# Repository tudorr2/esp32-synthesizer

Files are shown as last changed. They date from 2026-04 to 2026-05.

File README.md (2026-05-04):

---








---

## ◈

It's a tiny standalone synthesizer built from scratch on a handmade PCB, housed in a 3D-printed PLA enclosure. It generates polyphonic sawtooth wave audio through a low-pass filter with 3-voice detuning — all in real-time on the ESP32's DAC output, amplified through a PAM8403 into a 3mm speaker.

> **Inspired by and adapted from** → [`todbot/mozzi_experiments`](https://github.com/todbot/mozzi_experiments)
> The core logic and tone architecture draws heavily from todbot's work. I translated the original Python-based concepts to C++, rewired the patterns, reworked the tone arrays, and adapted the whole thing to run on the ESP32.

---

## ◈ Hardware

| Component | Role |
|---|---|
| **ESP32** (30-pin dev board) | Brain — runs audio ISR + sequencer logic |
| **PAM8403** | Class-D audio amplifier module |
| **40mm Speaker** | Audio output |
| **2× Potentiometers** | Root note + BPM control |
| **2× Tactile Buttons** | Pattern change + transpose control |
| **1× Slide/Toggle Switch** | Power / standby gate |
| **Handmade PCB** | Point-to-point etched board |
| **3D Printed PLA Case** | Custom enclosure, designed to fit the PCB snugly |

---

## ◈ Photos

## ◈ 3D Printed Case

> 📷 *PLA case 
case

---

> 📷 *Board 
board

---

>📷 *3D Model
3dcase

---

## ◈ Pin Map

```
ESP32 GPIO 36  ──  Knob A       (Root Note)
ESP32 GPIO 39  ──  Knob B       (BPM)
ESP32 GPIO 18  ──  Button A     (Change Pattern)
ESP32 GPIO 19  ──  Button B     (Transpose Step)
ESP32 GPIO 25  ──  DAC Out      → PAM8403 input
ESP32 GPIO 22  ──  LED          (Note trigger indicator)
ESP32 GPIO 15  ──  Power Switch 
```

---

## ◈ Controls

### 🎛 Knob A — Root Note
Sweeps the root note from **C1 (24)** to **C5 (72)**.
Turning it changes the key everything plays in — low and bassy to bright and cutting.

### 🎛 Knob B — Tempo (BPM)
Sets the playback speed from **40 BPM** to **180 BPM**.
Changes take effect immediately mid-pattern.

### 🔘 Button A — Cycle Pattern
Steps through the **15 built-in arpeggio patterns** one by one.
Each press advances to the next motif. Cycles back to the first after the last.

### 🔘 Button B — Transpose Steps
Cycles through **0 / 1 / 2 transpose steps** applied per loop.
With transpose active, each loop of the pattern shifts up by one octave (12 semitones), then wraps back — creating climbing or cascading phrases.

---

## ◈ Patterns

15 patterns, each 4 steps long. Intervals are in semitones from the root:

| # | Name | Steps | Character |
|---|---|---|---|
| 0 | `major` | 0, 4, 7, 12 | Bright, uplifting |
| 1 | `minor7th` | 0, 3, 7, 10 | Moody, jazzy edge |
| 2 | `diminished` | 0, 3, 6, 3 | Tense, unsettled |
| 3 | `suspended4th` | 0, 5, 7, 12 | Open, floating |
| 4 | `octaves` | 0, 12, 0, −12 | Classic octave pump |
| 5 | `octaves2` | 0, 12, 24, −12 | Wide, dramatic sweep |
| 6 | `octaves3` | 0, −12, −12, 0 | Deep sub-drop |
| 7 | `new1` | 0, 1, 1, 1 | Chromatic crawl |
| 8 | `new2` | 0, 12, 12, 12 | Locked-octave pulse |
| 9 | `power` | 0, 7, 12, 7 | Power chord vibe |
| 10 | `jazzy` | 0, 4, 7, 11 | Major 7th, smooth |
| 11 | `fifth-jump` | 0, 12, 7, 19 | Leaping fifths |
| 12 | `glitchy` | 0, 6, 13, 5 | Dissonant, broken |
| 13 | `leap` | 0, 30, 20, 10 | Wild interval jumps |
| 14 | `root` | 0, 0, 0, 0 | Drone / root lock |

---

## ◈ Code

The project is split into two files:

- Replaced Mozzi's audio scheduler with `esp_timer` periodic ISR at 44.1kHz
- Rewrote all note/timing logic in fixed-step float arithmetic
- Added 3-voice detuned oscillator chorus
- Reworked the arpeggio/motif tables with new patterns (`glitchy`, `leap`, `new1`, `new2`, `power`, `fifth-jump`)

> Full credit to **[todbot](https://github.com/todbot)** whose `mozzi_experiments` repo was the direct inspiration and starting point for the pattern sequencer architecture. This is an adaptation — most of the higher-level motif/sequencer logic structure came from his work.

---

## ◈Credits

-Concept and sequencer architecture adapted from **[todbot/mozzi_experiments](https://github.com/todbot/mozzi_experiments)**

---

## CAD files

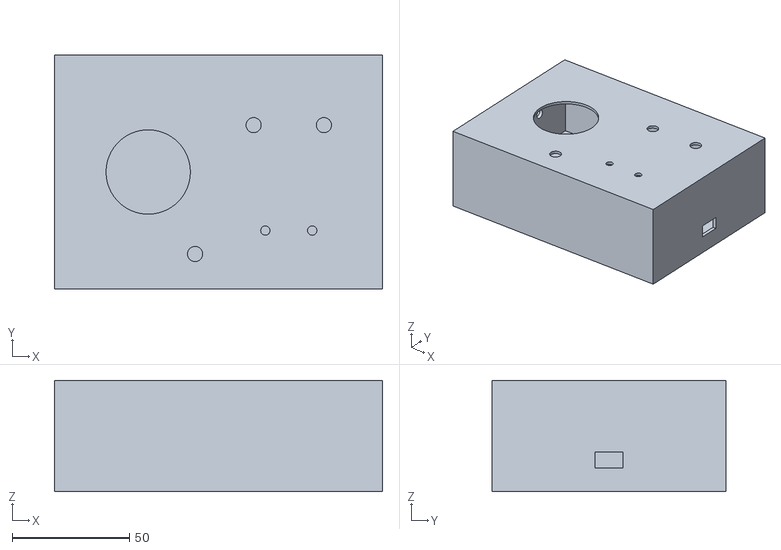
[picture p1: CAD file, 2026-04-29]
3d-case/case_esp32.stl
140.0 x 100.0 x 47.5

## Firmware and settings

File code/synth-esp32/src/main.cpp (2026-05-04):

#include <Arduino.h>
#include <driver/dac.h>
#include <esp_timer.h>
#include "lib.h"

#define PIN_KNOB_A 36
#define PIN_KNOB_B 39
#define PIN_BUTTON_A 14 // transpose steps
#define PIN_BUTTON_B 27 // mot pattern
#define PIN_DAC 25
#define PIN_LED 22
#define POWER_SW 15

#define SAMPLE_RATE 44100 // khz
#define NUM_VOICES 3
#define WAVE_LEN 512

int16_t wave_saw[WAVE_LEN];

struct Voice
{
  float phase;
  float freq;
  float lpf_out;
  float lpf_cutoff;
};
Voice voices[NUM_VOICES];

volatile float amp_level = 0.0f; // changes inside the isr
volatile float amp_target = 0.0f;
const float ATTACK_RATE = 1.0f / (0.01f * SAMPLE_RATE); // how fast it goes to 100; fade-in rate
const float RELEASE_RATE = 1.0f / (0.3f * SAMPLE_RATE);

float knobAval = 0, knobBval = 0;
const float KNOB_FILTER = 0.8f;

bool lastBtnA = HIGH, lastBtnB = HIGH;
unsigned long lastBtnAms = 0, lastBtnBms = 0;
const unsigned long DEBOUNCE_MS = 50; // waiting period after the btn press

Motif motif;

float midi_to_hz(int note)
{
  return 440.0f * powf(2.0f, (note - 69) / 12.0f);
}

float map_range(float s, float a1, float a2, float b1, float b2)
{
  return b1 + ((s - a1) * (b2 - b1) / (a2 - a1));
}

void note_on(int n)
{
  Serial.printf("  note on  %d\n", n);
  digitalWrite(PIN_LED, HIGH);

  float fo = midi_to_hz(n);
  for (int i = 0; i < NUM_VOICES; i++)
  {
    voices[i].freq = fo * (1.0f + i * 0.007f);
    float cutoff = (fo * 8.0f) / (SAMPLE_RATE / 2.0f);
    voices[i].lpf_cutoff = constrain(cutoff, 0.05f, 0.9f);
  }
  amp_target = 1.0f;
}

void note_off(int n)
{
  Serial.printf("  note off %d\n", n);
  digitalWrite(PIN_LED, LOW);
  amp_target = 0.0f;
}

void audio_isr(void *arg) // interrupt service routine
{

  // volume fade-in
  if (amp_level < amp_target)
  {
    amp_level += ATTACK_RATE;
    if (amp_level > amp_target)
      amp_level = amp_target;
  } // fade-out
  else if (amp_level > amp_target)
  {
    amp_level -= RELEASE_RATE;
    if (amp_level < 0.0f)
      amp_level = 0.0f;
  }

  if (amp_level <= 0.001f)
  {
    dacWrite(PIN_DAC, 128);
    return;
  }

  float mixed = 0.0f;
  for (int v = 0; v < NUM_VOICES; v++)
  {
    voices[v].phase += voices[v].freq / (float)SAMPLE_RATE; // phase accumulator
    if (voices[v].phase >= 1.0f)
      voices[v].phase -= 1.0f;

    int idx = (int)(voices[v].phase * (WAVE_LEN - 1));
    float sample = wave_saw[idx] / 32768.0f;

    float c = voices[v].lpf_cutoff;
    voices[v].lpf_out += c * (sample - voices[v].lpf_out); // low pass filter
    mixed += voices[v].lpf_out;
  }

  mixed = (mixed / (float)NUM_VOICES) * amp_level;

  int dac_val = (int)(mixed * 90.0f) + 128;

  dacWrite(PIN_DAC, (uint8_t)constrain(dac_val, 0, 255));
}

void setup()
{
  Serial.begin(115200);
  delay(1000);

  for (int i = 0; i < WAVE_LEN; i++)
  {
    wave_saw[i] = (int16_t)(30000 - (60000 * i / WAVE_LEN));
  }

  pinMode(PIN_BUTTON_A, INPUT_PULLUP);
  pinMode(PIN_BUTTON_B, INPUT_PULLUP);
  pinMode(POWER_SW, INPUT_PULLUP);
  pinMode(PIN_LED, OUTPUT);

  dac_output_enable(DAC_CHANNEL_1);
  dacWrite(PIN_DAC, 128);

  esp_timer_handle_t audio_timer;
  const esp_timer_create_args_t timer_args = {
      .callback = &audio_isr,
      .arg = NULL,
      .dispatch_method = ESP_TIMER_TASK, // run the audio in a high priority background
      .name = "audio_isr"};
  esp_timer_create(&timer_args, &audio_timer);
  esp_timer_start_periodic(audio_timer, 1000000 / SAMPLE_RATE); // every 22.6ms

  motif.note_on_handler = note_on;
  motif.note_off_handler = note_off;
  motif.on();
  motif.root_note = 37;
  motif.set_mot("suspended4th");
  motif.set_bpm(110, 4);

  Serial.println("Ready");
}

bool lastPowerState = false; 

void loop()
{
  bool powerOn = digitalRead(POWER_SW) == LOW;

  if (!powerOn)
  {
    if (lastPowerState) 
    {
      motif.off();
      amp_target = 0.0f;
      dacWrite(PIN_DAC, 128);
      digitalWrite(PIN_LED, LOW);
      Serial.println("Standby");
    }
    lastPowerState = false;
    return;
  }

  if (!lastPowerState) 
  {
    motif.on();
    Serial.println("Running");
  }
  lastPowerState = true;

  bool btnA = digitalRead(PIN_BUTTON_A);
  if (btnA == LOW && lastBtnA == HIGH && (millis() - lastBtnAms > DEBOUNCE_MS))
  {
    motif.next_mot();
    Serial.print("Pattern: ");
    Serial.println(motif.mot_name());
    lastBtnAms = millis();
  }
  lastBtnA = btnA;

  bool btnB = digitalRead(PIN_BUTTON_B);
  if (btnB == LOW && lastBtnB == HIGH && (millis() - lastBtnBms > DEBOUNCE_MS))
  {
    int steps = (motif.trans_steps + 1) % 3;
    motif.set_transpose(12, steps);
    Serial.printf("Transpose Steps: %d\n", steps);
    lastBtnBms = millis();
  }
  lastBtnB = btnB;

  knobAval = (knobAval * KNOB_FILTER) + (1.0f - KNOB_FILTER) * analogRead(PIN_KNOB_A);
  knobBval = (knobBval * KNOB_FILTER) + (1.0f - KNOB_FILTER) * analogRead(PIN_KNOB_B);

  motif.root_note = (int)map_range(knobAval, 0, 4095, 24, 72);
  motif.set_bpm(map_range(knobBval, 0, 4095, 40, 180));

  motif.update();
}

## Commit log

2026-04-29 changed
    Removed sections for photos and 3D printed case from README.
2026-04-29 changed on/off logic
    [case_esp32.stl]
2026-05-04 Revise photo section in README
    Updated photo descriptions and added images for the board and case.
